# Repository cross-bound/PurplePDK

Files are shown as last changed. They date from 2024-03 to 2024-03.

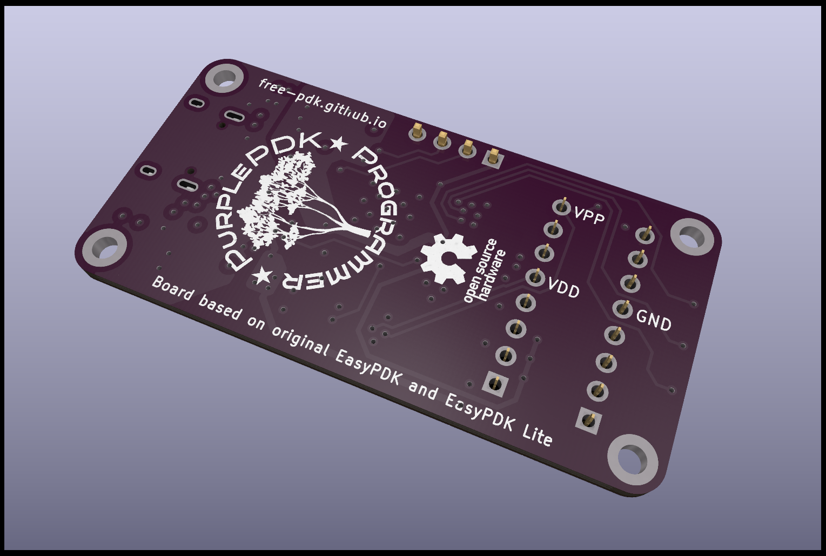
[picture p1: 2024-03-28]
IMG/PurplePDK_back.png

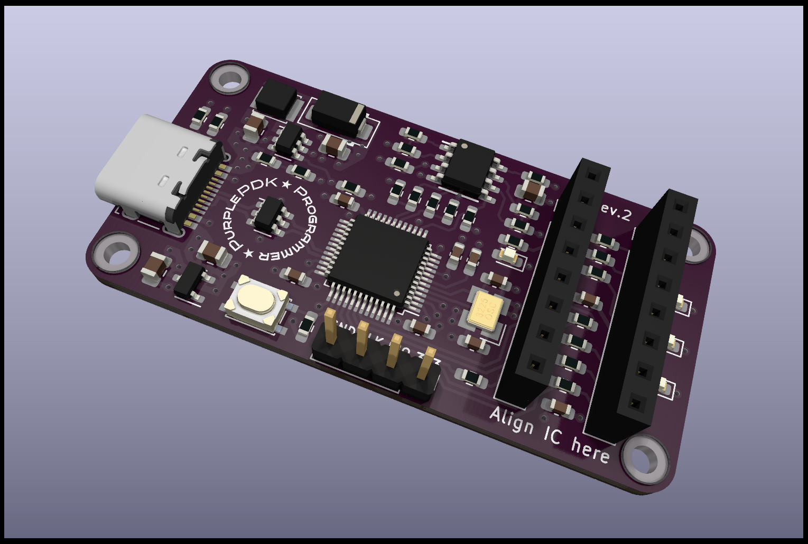
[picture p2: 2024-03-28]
IMG/PurplePDK_front.png

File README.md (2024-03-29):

PCB_Render

Purple PDK is a redesign of the [Original FreePDK](https://free-pdk.github.io/) and [easy-pdk-programmer-lite](https://github.com/free-pdk/easy-pdk-programmer-lite-hardware) programmers. It was to challange myself and practice PCB design. It was tested with the Padauk PFS-154. Should work with the all other MCU's that are supported by the original FreePDK programmer.

The board is a 4 layer board with the two inner layers being solid ground planes. The size of the PCB is small enough that it can be ordered unassambled from JLCPCB for $2 (at the time of this writing. With purple solder mask and order number removed it's around $8 for 5 boards).

Changes to the easy-pdk-programmer-lite schematic were made to use a SMD type oscillator. The mircoUSB port was changed to Type-C. Also added was a ESD protection IC which may or may not be needed.

Capacitors, resistors, and LEDs are mostly 0603, plus a few 0805 caps. The pads for 0603 components are slightly extended for hand soldering. But this is definitly not a beginner friendly soldering project.

Dimensions: 52x26mm

PCB

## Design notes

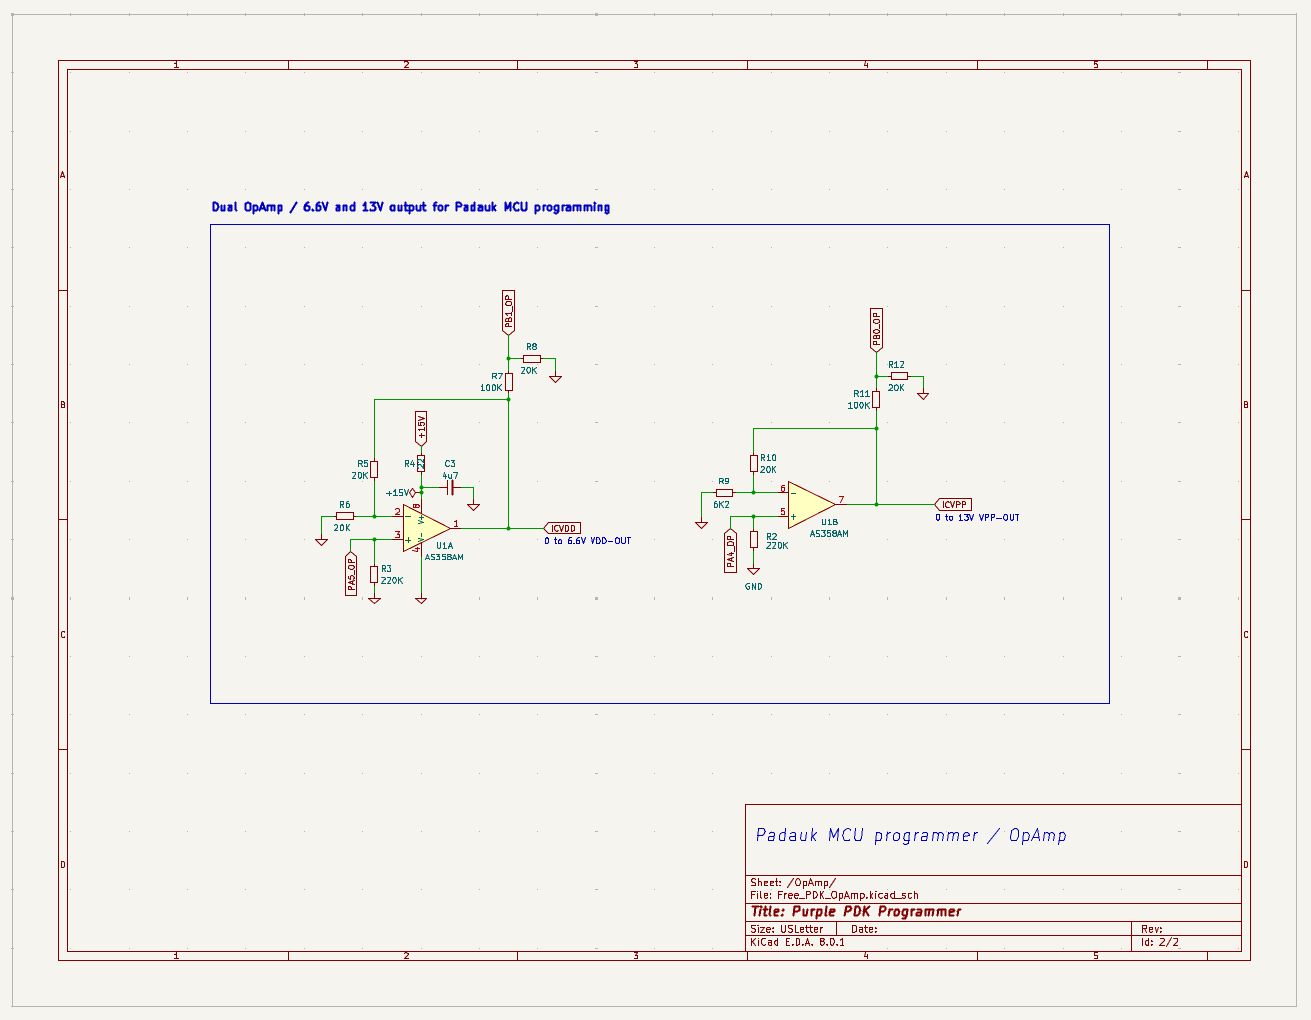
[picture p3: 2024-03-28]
IMG/Schematic_OPAMP.PNG

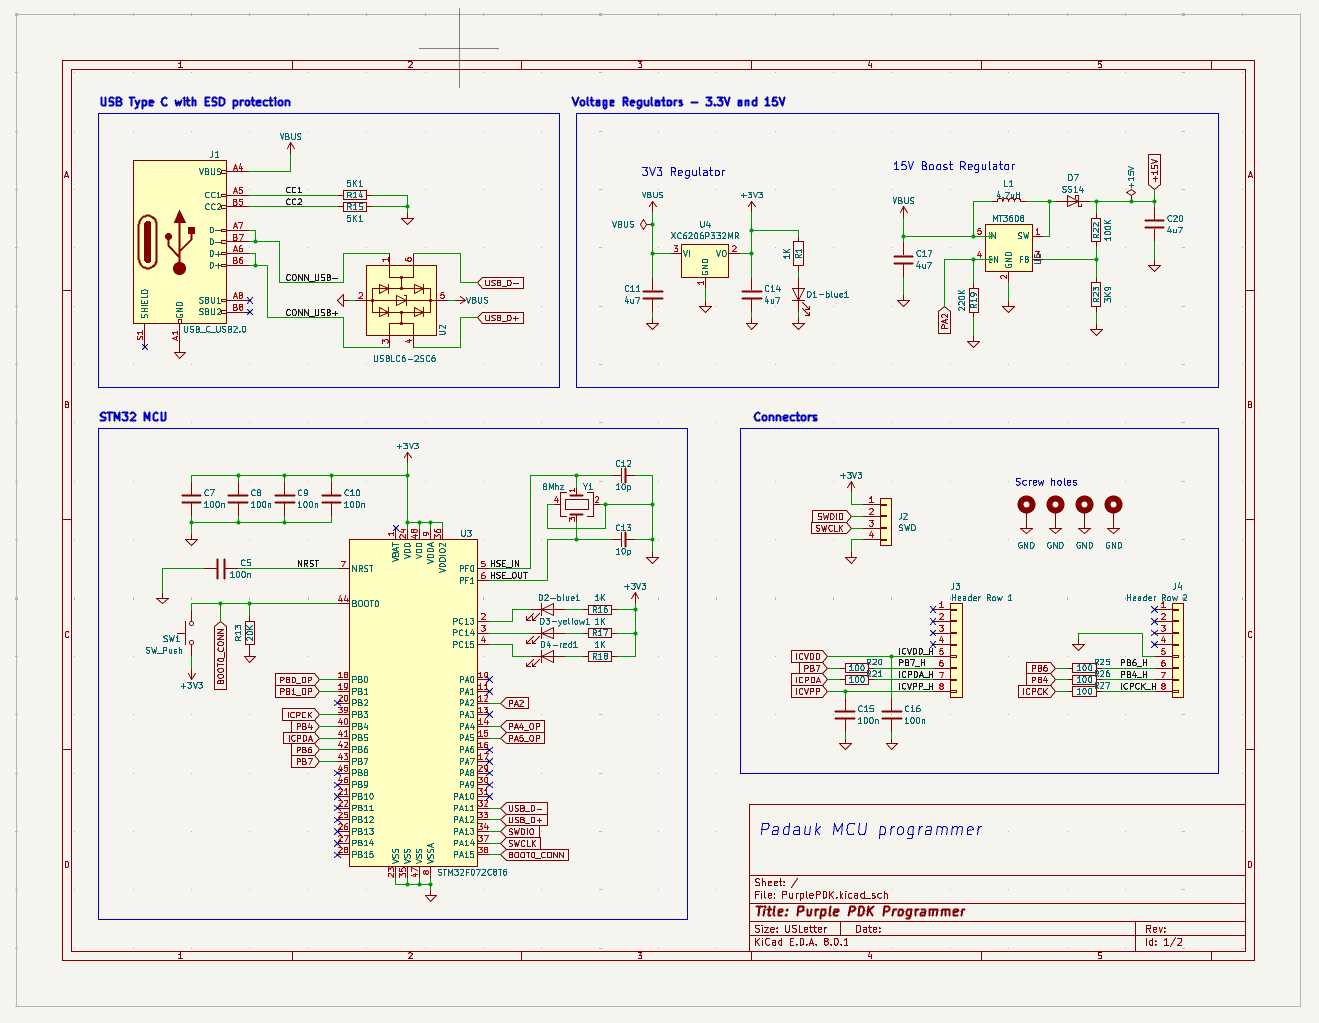
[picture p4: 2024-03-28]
IMG/Schematic.PNG

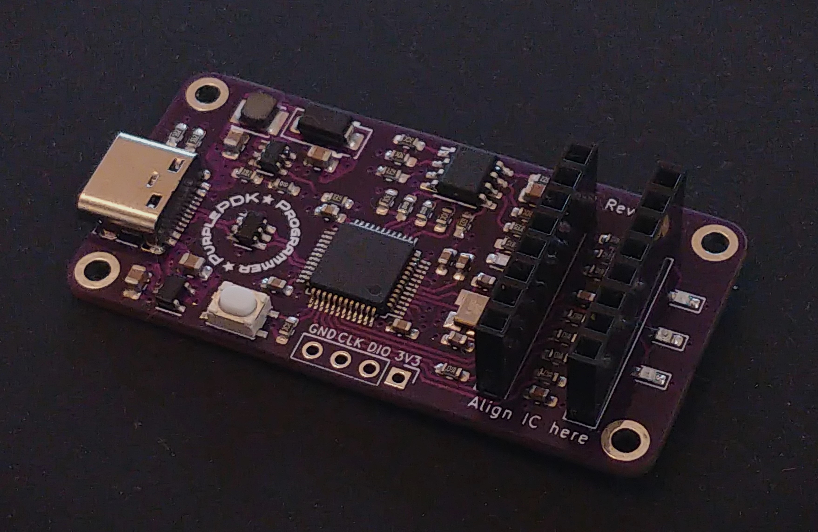
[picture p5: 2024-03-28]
IMG/PCB_front.jpg

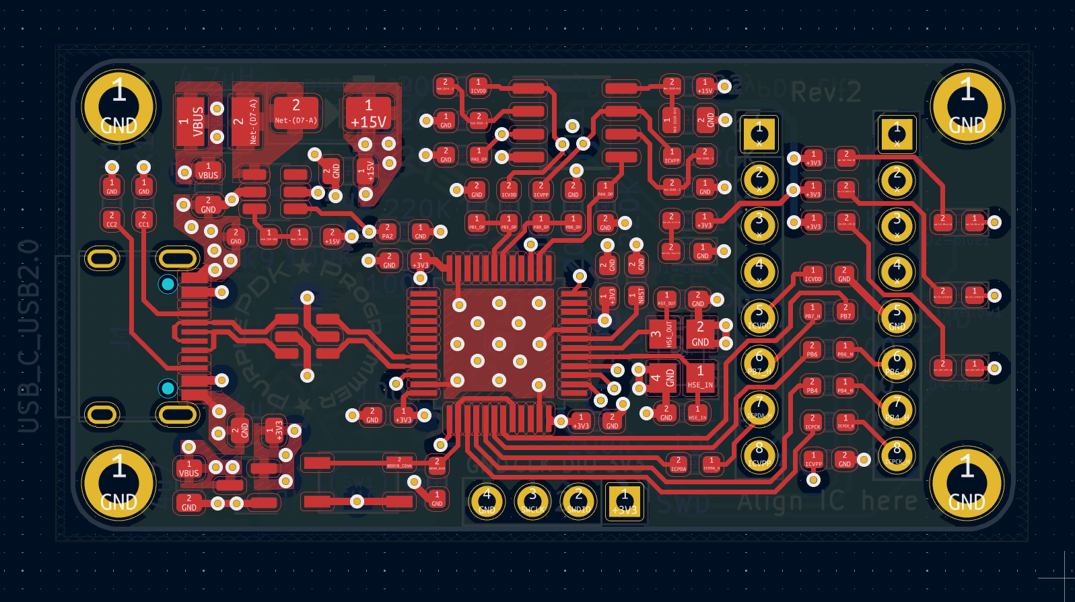
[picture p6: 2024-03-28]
IMG/PCB.PNG

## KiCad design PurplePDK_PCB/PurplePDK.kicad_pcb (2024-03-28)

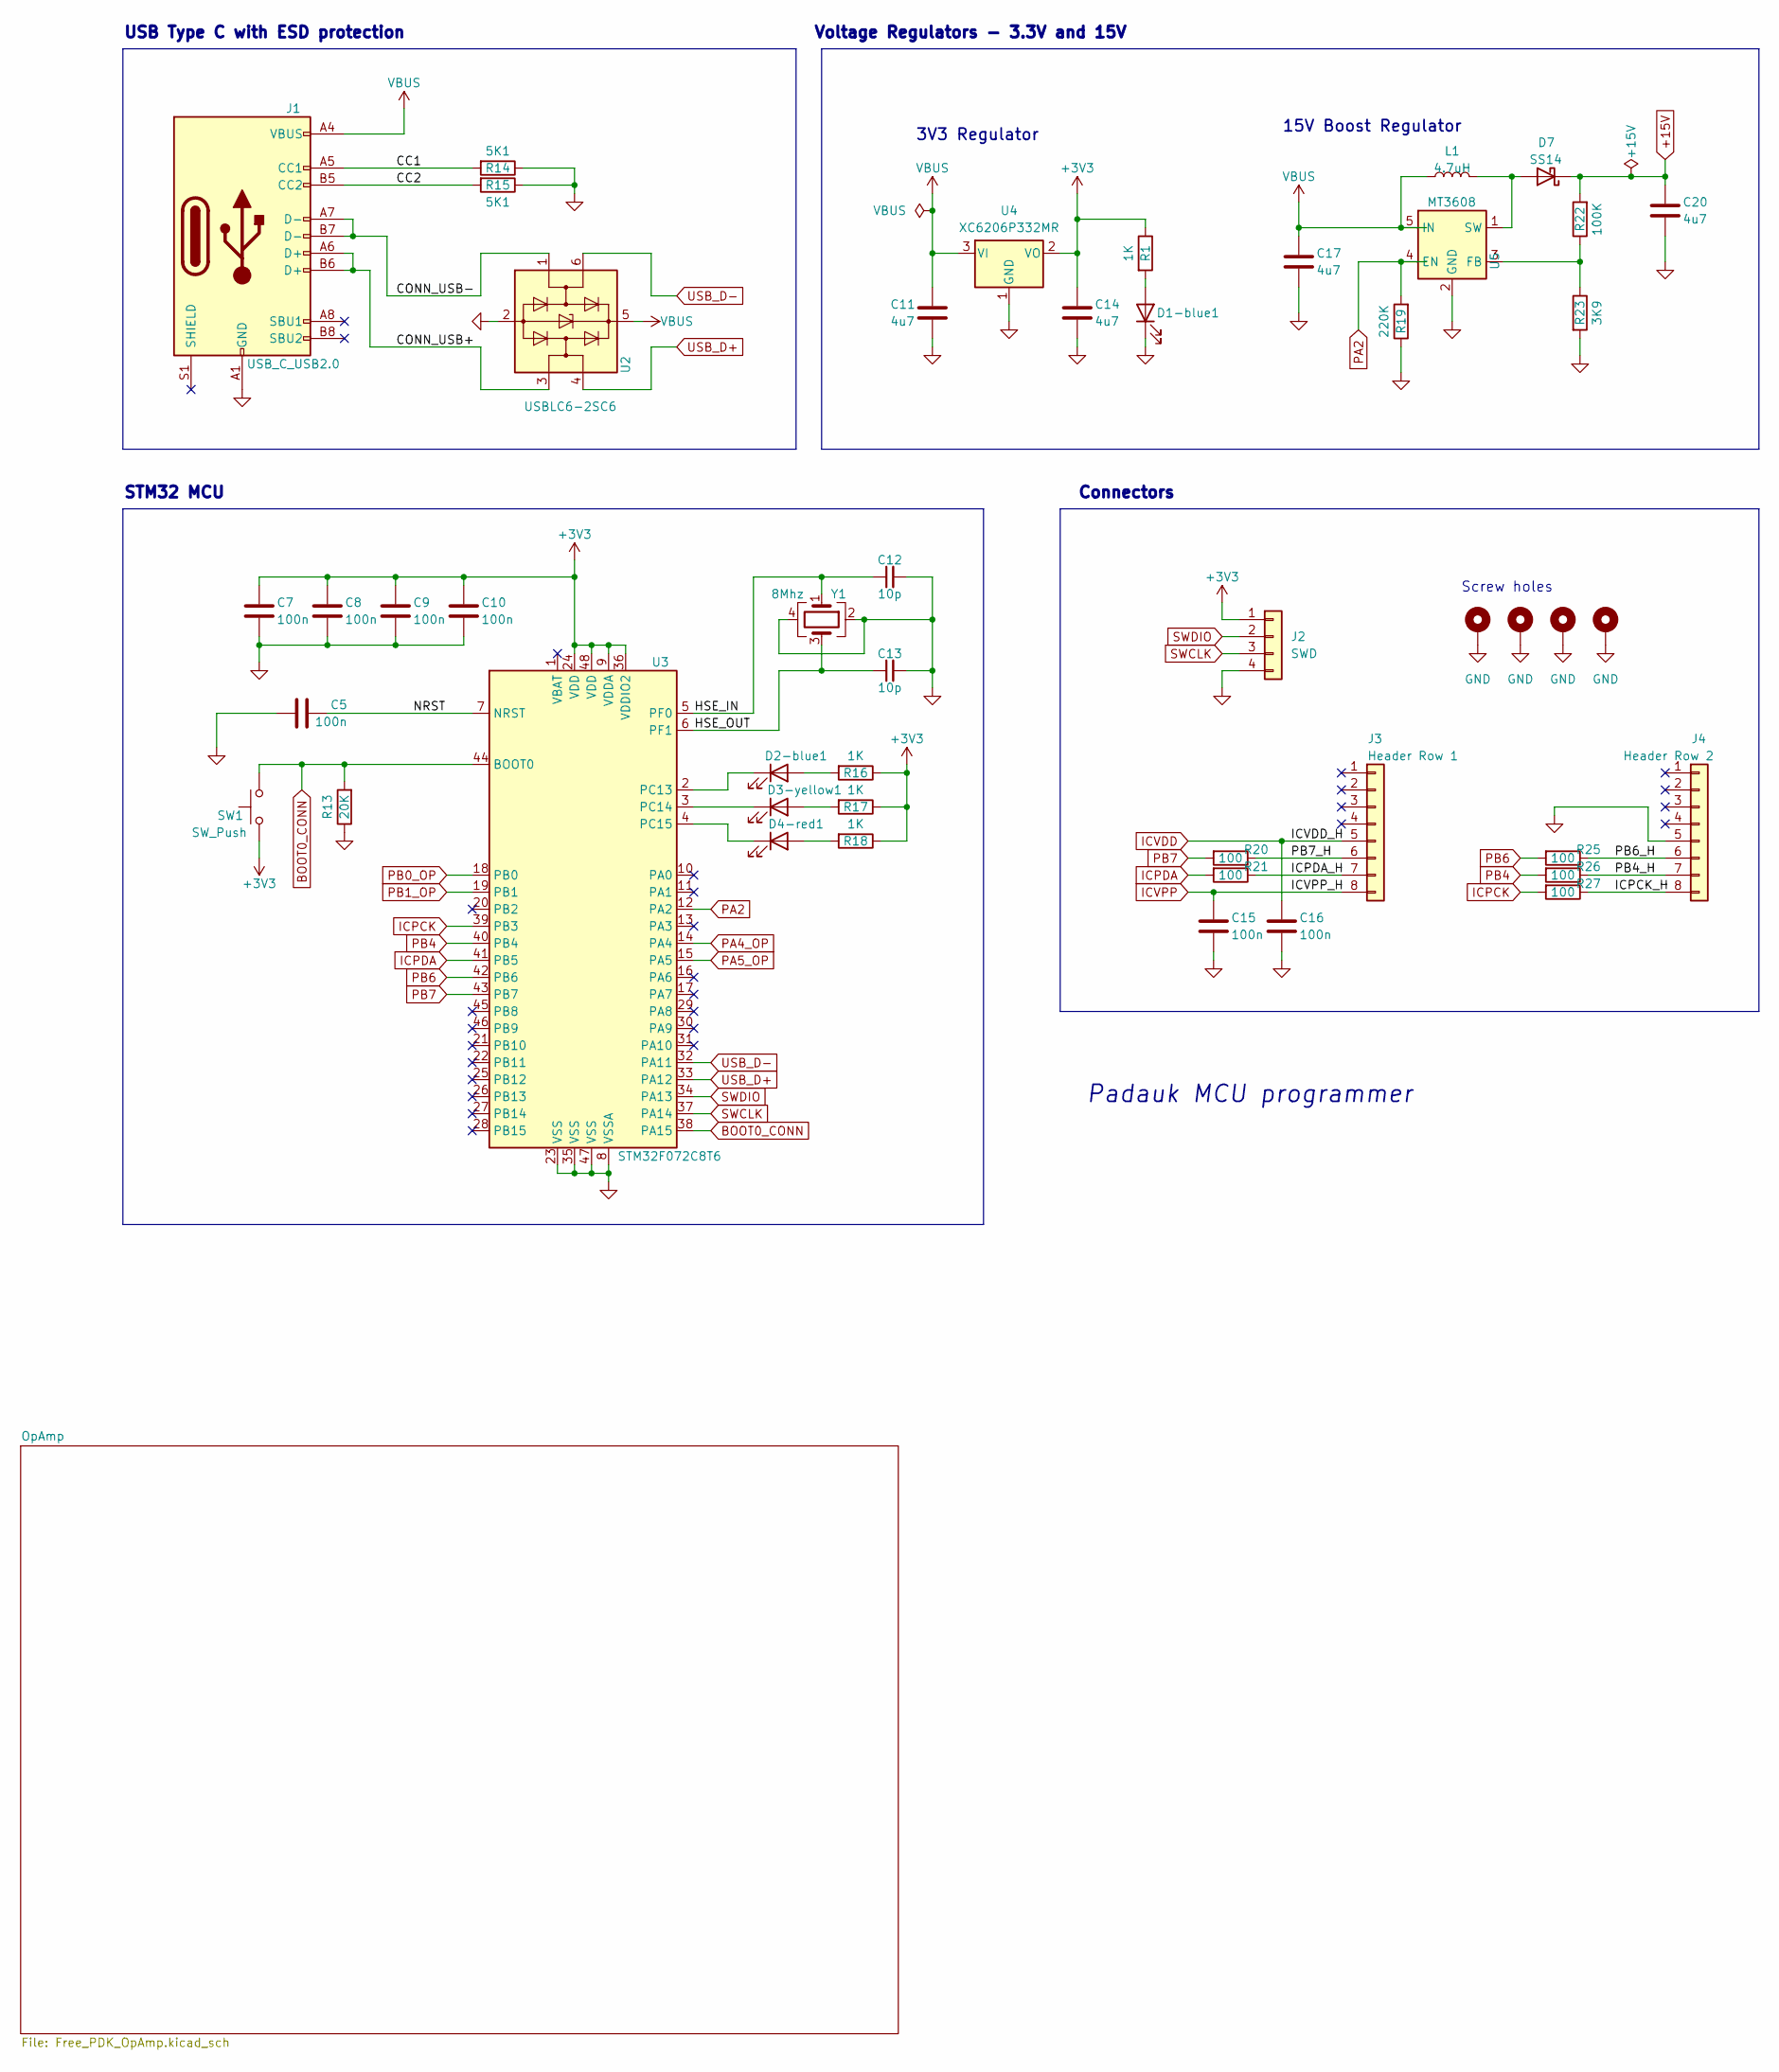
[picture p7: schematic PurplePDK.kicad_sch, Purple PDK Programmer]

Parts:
C5, C7, C8, C9, C10, C15, C16: 100n; C_0603_1608Metric_Pad1.08x0.95mm_HandSolder
C11, C14, C17, C20: 4u7; C_0805_2012Metric
C12, C13: 10p; C_0603_1608Metric_Pad1.08x0.95mm_HandSolder
D1-blue1, D2-blue1, D3-yellow1, D4-red1: LED; LED_0603_1608Metric_Pad1.05x0.95mm_HandSolder
D7: SS14; D_SMA
H1, H2, H3, H4: MountingHole_Pad; MountingHole_2.2mm_M2_ISO14580_Pad
J1: USB_C_USB2.0; USB_C_Receptacle_HRO_TYPE-C-31-M-12
J2: SWD; PinHeader_1x04_P2.54mm_Vertical
J3: Header Row 1; PinHeader_1x08_P2.54mm_Vertical
J4: Header Row 2; PinHeader_1x08_P2.54mm_Vertical
L1: 4.7uH; L_Sunlord_SWPA3015S
R1, R16, R17, R18: 1K; R_0603_1608Metric_Pad0.98x0.95mm_HandSolder
R13: 20K; R_0603_1608Metric_Pad0.98x0.95mm_HandSolder
R14, R15: 5K1; R_0603_1608Metric_Pad0.98x0.95mm_HandSolder
R19: 220K; R_0603_1608Metric_Pad0.98x0.95mm_HandSolder
R20, R21, R25, R26, R27: 100; R_0603_1608Metric_Pad0.98x0.95mm_HandSolder
R22: 100K; R_0603_1608Metric_Pad0.98x0.95mm_HandSolder
R23: 3K9; R_0603_1608Metric_Pad0.98x0.95mm_HandSolder
SW1: SW_Push; SW_SPST_PTS810
U2: USBLC6-2SC6; SOT-23-6
U3: STM32F072C8T6; LQFP-48_7x7mm_P0.5mm
U4: XC6206P332MR; SOT-23
U5: MT3608; SOT-23-6
Y1: 8Mhz; Oscillator_SMD_Abracon_ASE-4Pin_3.2x2.5mm_HandSoldering

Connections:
+3V3: C7.1, C8.1, C9.1, C10.1, C14.1, J2.1, R1.1, R16.1, R17.1, R18.1, SW1.1, U3.9 (VDDA), U3.24 (VDD), U3.36 (VDDIO2), U3.48 (VDD), U4.2 (VO)
+15V: C20.1, D7.1 (K), R22.2; also elsewhere on the board
/CC1: J1.A5 (CC1), R14.2
/CC2: J1.B5 (CC2), R15.2
/CONN_USB+: J1.A6 (D+), J1.B6 (D+), U2.3 (I/O2)
/CONN_USB-: J1.A7 (D-), J1.B7 (D-), U2.1 (I/O1)
/HSE_IN: C12.1, U3.5 (PF0), Y1.1
/HSE_OUT: C13.1, U3.6 (PF1), Y1.3
/ICPCK_H: J4.8, R27.1
/ICPDA_H: J3.7, R21.1
/PB4_H: J4.7, R26.1
/PB6_H: J4.6, R25.1
/PB7_H: J3.6, R20.1
BOOT0_CONN: R13.2, SW1.2, U3.38 (PA15), U3.44 (BOOT0)
ICPCK: R27.2, U3.39 (PB3)
ICPDA: R21.2, U3.41 (PB5)
ICVDD: C16.1, J3.5; also elsewhere on the board
ICVPP: C15.1, J3.8; also elsewhere on the board
unnamed: D1-blue1.2 (A), R1.2
unnamed: D2-blue1.2 (A), R16.2
unnamed: D2-blue1.1 (K), U3.2 (PC13)
unnamed: D3-yellow1.2 (A), R17.2
unnamed: D3-yellow1.1 (K), U3.3 (PC14)
unnamed: D4-red1.2 (A), R18.2
unnamed: D4-red1.1 (K), U3.4 (PC15)
unnamed: D7.2 (A), L1.2, U5.1 (SW)
unnamed: R22.1, R23.1, U5.3 (FB)
PA2: R19.2, U3.12 (PA2), U5.4 (EN)
PA4_OP: U3.14 (PA4); also elsewhere on the board
PA5_OP: U3.15 (PA5); also elsewhere on the board
PB0_OP: U3.18 (PB0); also elsewhere on the board
PB1_OP: U3.19 (PB1); also elsewhere on the board
PB4: R26.2, U3.40 (PB4)
PB6: R25.2, U3.42 (PB6)
PB7: R20.2, U3.43 (PB7)
SWCLK: J2.3, U3.37 (PA14)
SWDIO: J2.2, U3.34 (PA13)
USB_D+: U2.4 (I/O2), U3.33 (PA12)
USB_D-: U2.6 (I/O1), U3.32 (PA11)
VBUS: C11.1, C17.1, J1.A4 (VBUS), J1.A9 (VBUS), J1.B4 (VBUS), J1.B9 (VBUS), L1.1, U2.5 (VBUS), U4.3 (VI), U5.5 (IN)

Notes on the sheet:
Screw holes
Connectors
15V Boost Regulator
STM32 MCU
3V3 Regulator
Padauk MCU programmer
Voltage Regulators - 3.3V and 15V
USB Type C with ESD protection

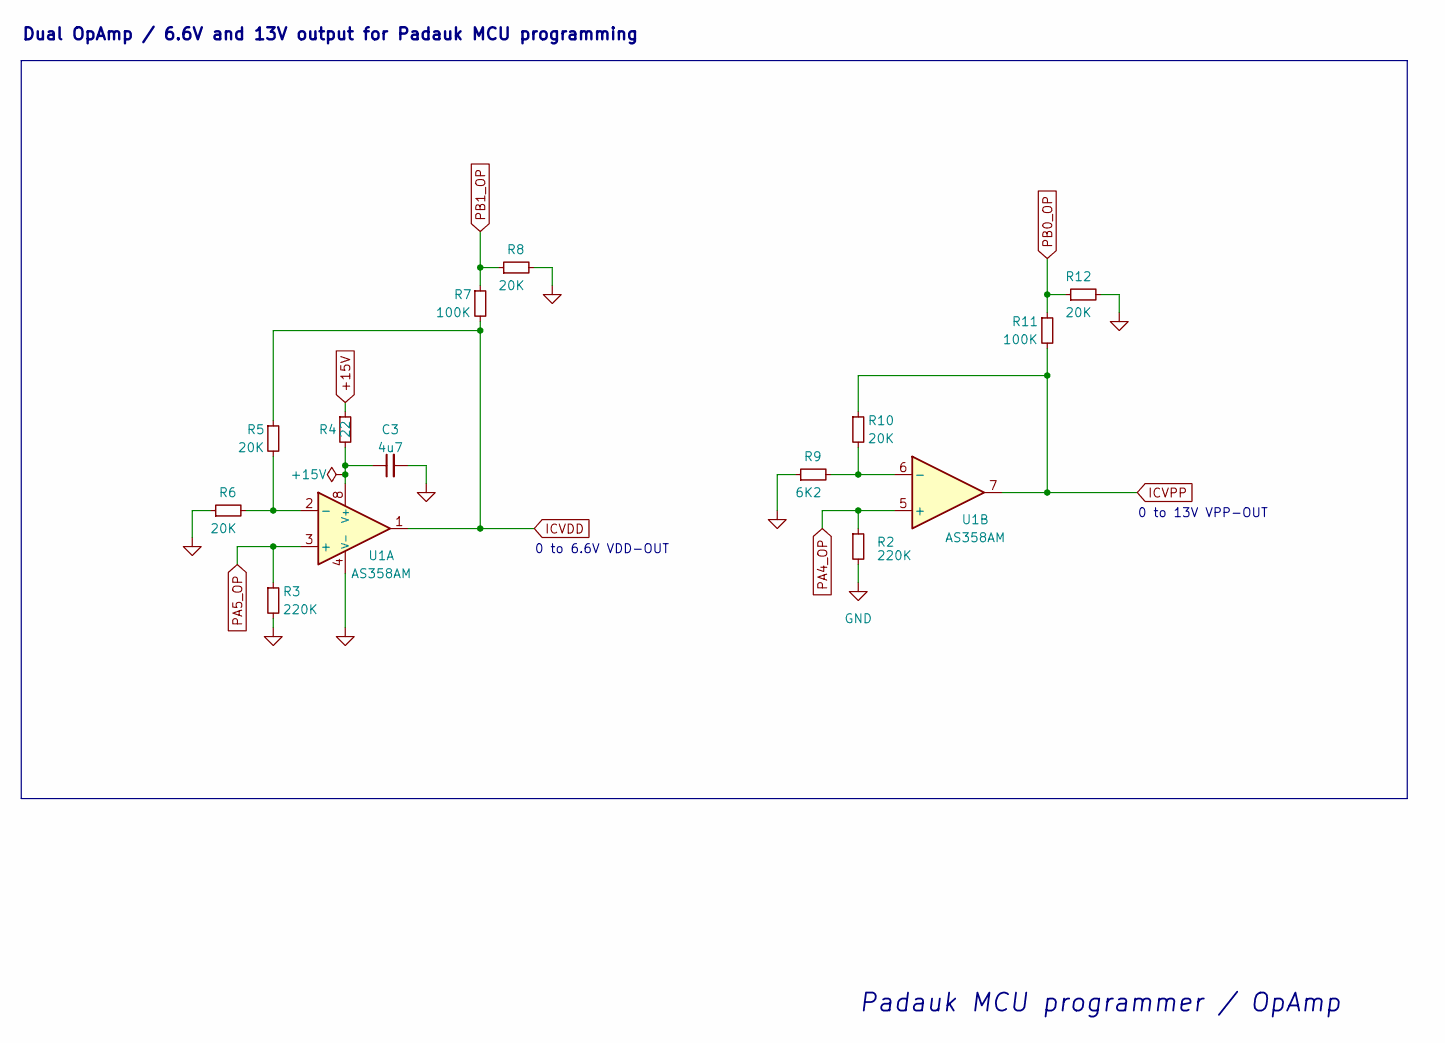
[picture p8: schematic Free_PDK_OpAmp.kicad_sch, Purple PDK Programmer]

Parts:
C3: 4u7; C_0805_2012Metric
R2, R3: 220K; R_0603_1608Metric_Pad0.98x0.95mm_HandSolder
R4: 22; R_0603_1608Metric_Pad0.98x0.95mm_HandSolder
R5, R6, R8, R10, R12: 20K; R_0603_1608Metric_Pad0.98x0.95mm_HandSolder
R7, R11: 100K; R_0603_1608Metric_Pad0.98x0.95mm_HandSolder
R9: 6K2; R_0603_1608Metric_Pad0.98x0.95mm_HandSolder
U1: AS358AM; SO-8_3.9x4.9mm_P1.27mm

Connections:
+15V: R4.1; also elsewhere on the board
ICVDD: R5.1, R7.2, U1.1; also elsewhere on the board
ICVPP: R10.1, R11.2, U1.7; also elsewhere on the board
unnamed: R5.2, R6.2, U1.2 (-)
unnamed: C3.1, R4.2, U1.8 (V+)
unnamed: R9.2, R10.2, U1.6 (-)
PA4_OP: R2.1, U1.5 (+); also elsewhere on the board
PA5_OP: R3.1, U1.3 (+); also elsewhere on the board
PB0_OP: R11.1, R12.1; also elsewhere on the board
PB1_OP: R7.1, R8.1; also elsewhere on the board

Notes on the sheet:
Padauk MCU programmer / OpAmp
Dual OpAmp / 6.6V and 13V output for Padauk MCU programming
0 to 6.6V VDD-OUT
0 to 13V VPP-OUT

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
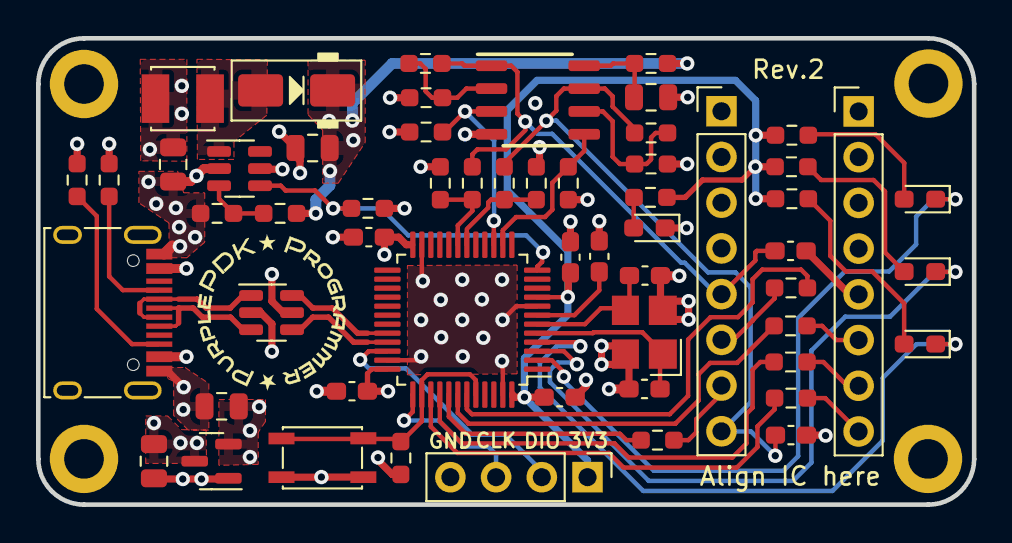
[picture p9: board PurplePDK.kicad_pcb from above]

Board: 4 copper layers, 52.0 x 25.9 mm, 61 parts (0 on the bottom side), 45 nets.

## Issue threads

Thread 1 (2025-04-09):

No BOM or PNP in project

AlexGubia, 2025-04-09:
Missing files for PCBA or part ordering.
